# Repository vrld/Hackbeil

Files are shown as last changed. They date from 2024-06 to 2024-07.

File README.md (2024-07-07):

# Hackbeil (/ˈhakˌbaɪ̯l/)

My custom 60 key wireless split keyboard. Inspired by [Lily58](https://github.com/kata0510/Lily58). (Will be) Built with [ergogen](https://ergogen.xyz) and [zmk](https://zmk.dev).

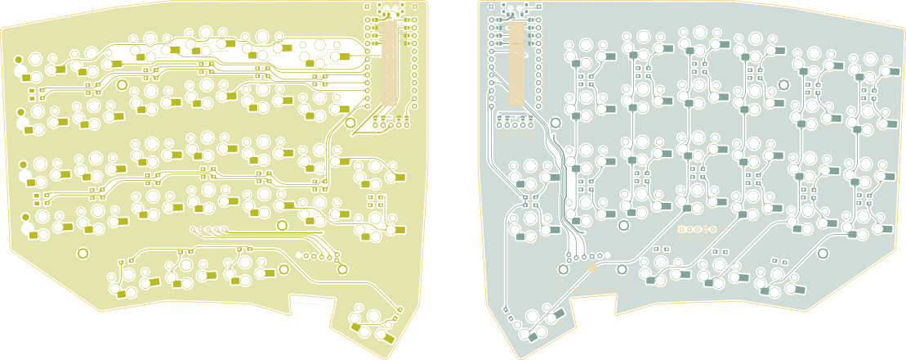
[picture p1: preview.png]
screenshot of the pcb, routed


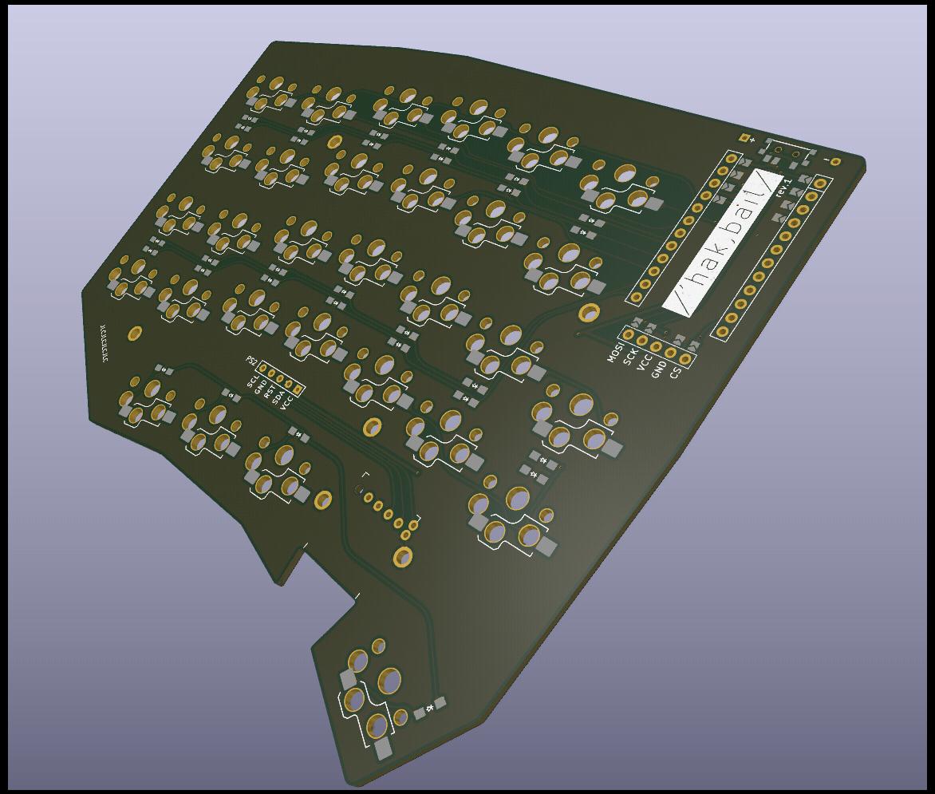
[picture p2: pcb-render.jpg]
rendering of the pcb


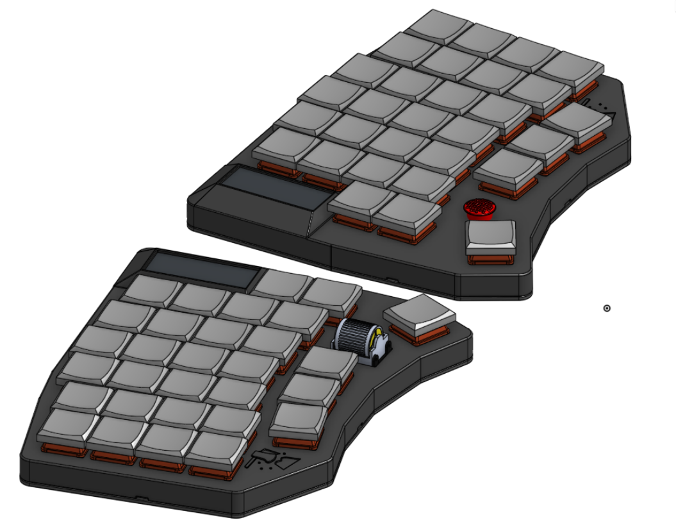
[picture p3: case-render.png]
rendering of the 3d printed case


## Setup

Install ergogen, e.g., with `yarn`:

    yarn global add ergogen

## Building

Using `make`:

    make

The output will be placed in the `build` directory.

Next, use KiCad to add traces or try your luck with freerouting.
That will likely require some modifications to the footprints though.

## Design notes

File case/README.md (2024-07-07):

The case was designed with onshape. Find the document [here](https://cad.onshape.com/documents/a196e7cfe793f017acaf2613/w/5e54595bcd19ec8f7b065f1a/e/1e5f3f1594b05356b8aebbdb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).

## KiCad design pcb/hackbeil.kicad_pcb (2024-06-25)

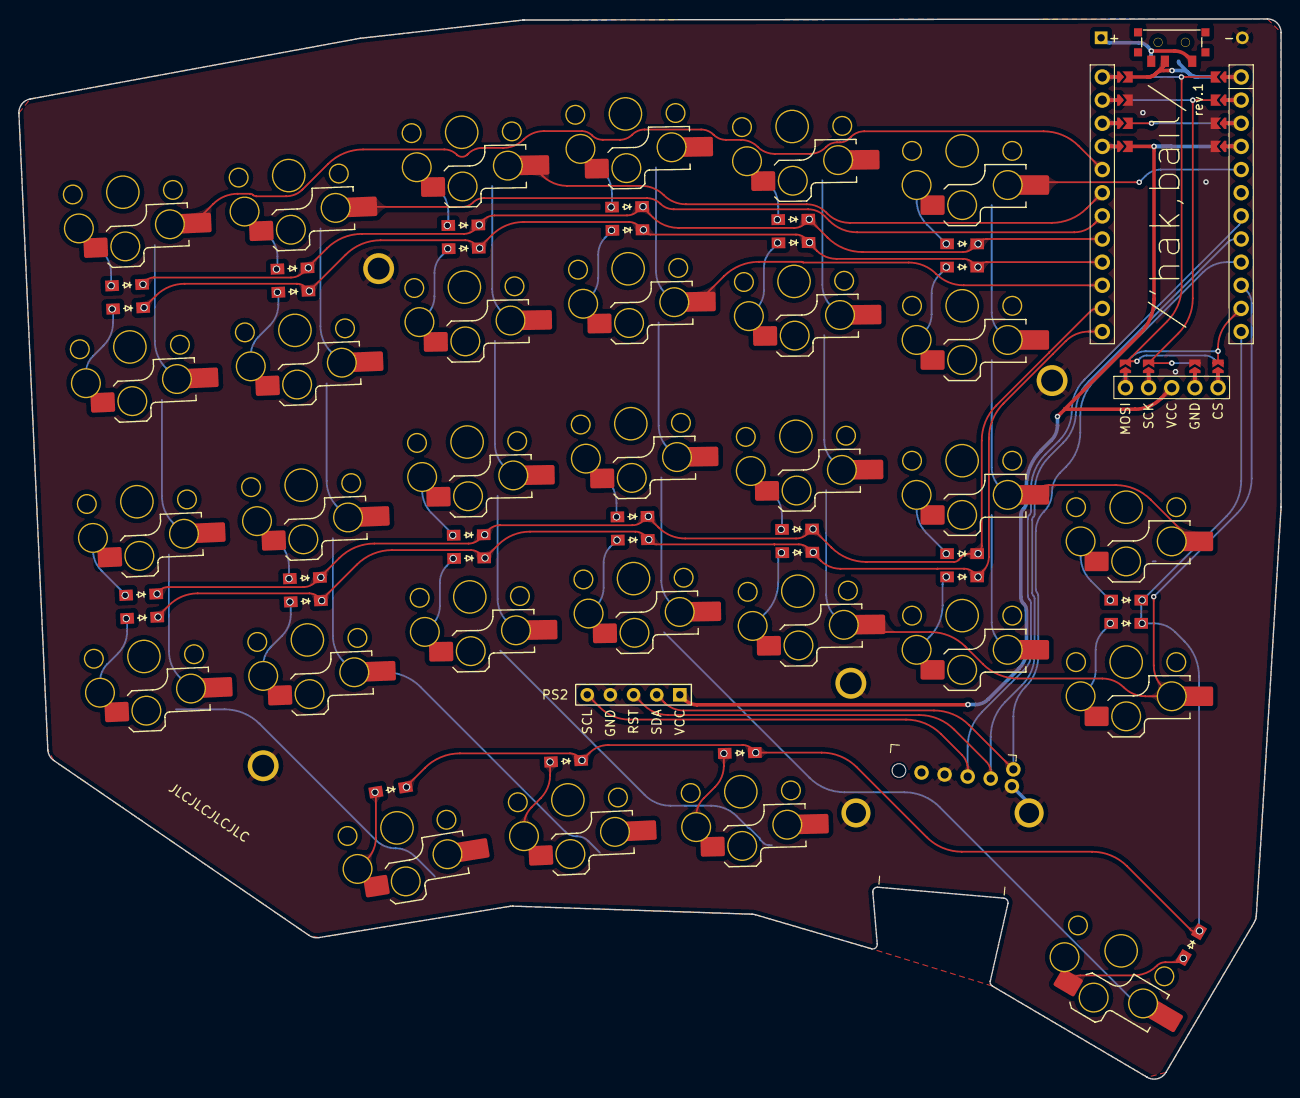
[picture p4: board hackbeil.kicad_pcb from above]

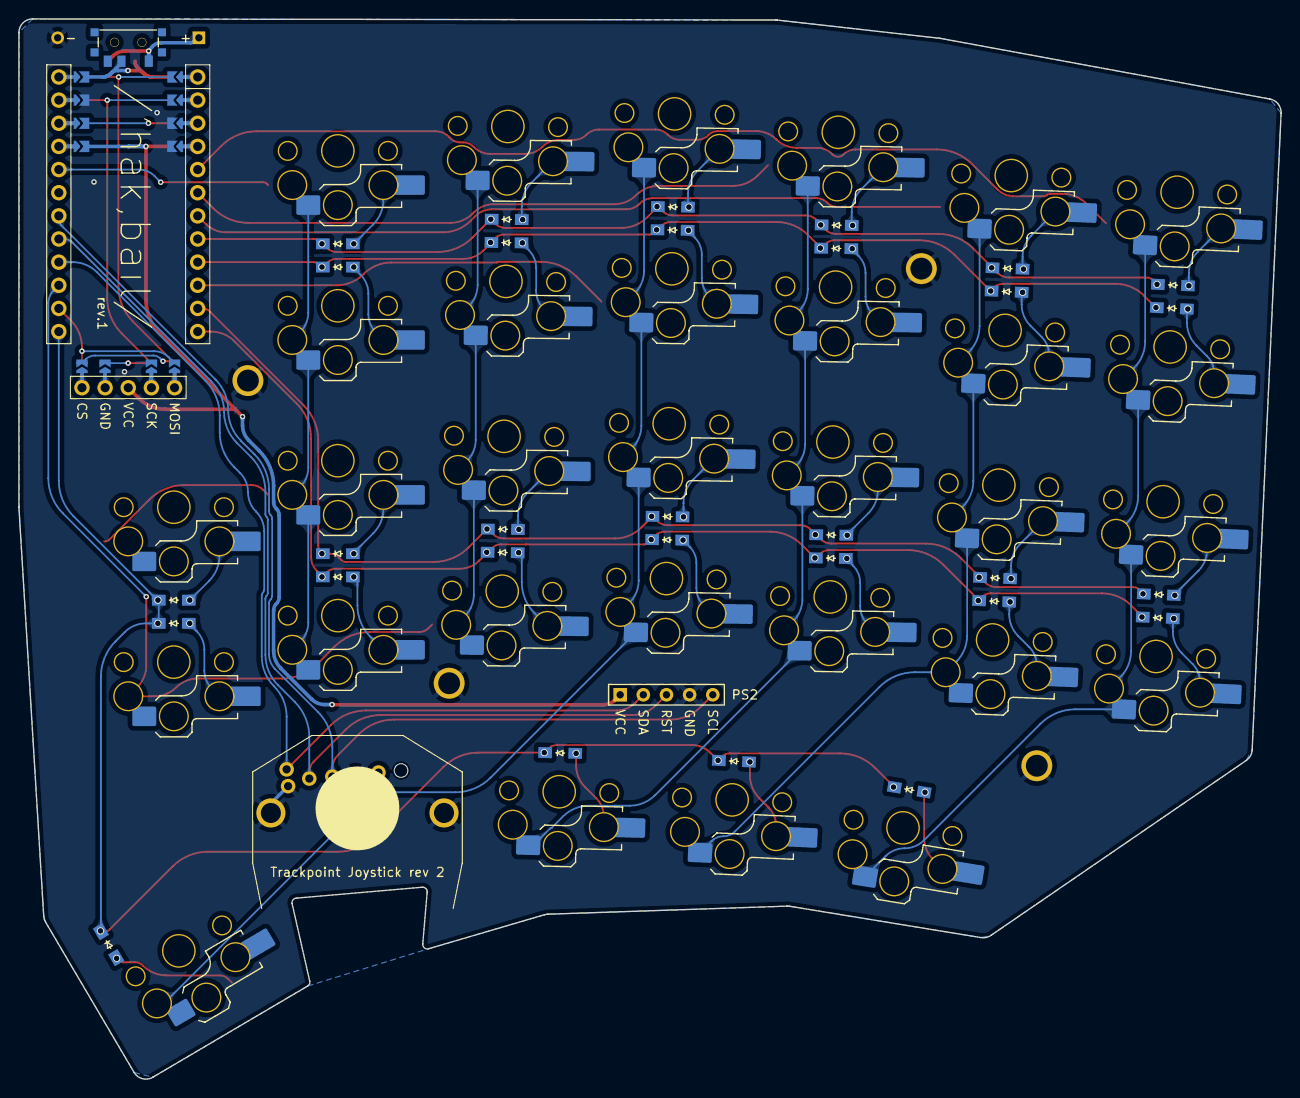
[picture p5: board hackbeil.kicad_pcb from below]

Board: 2 copper layers, 138.5 x 116.3 mm, 71 parts (31 on the bottom side), 55 nets.

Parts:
BAT1: battery
D1, D2, D3, D4, D5, D6, D7, D8, D9, D10, D11, D12, D13, D14, D15, D16, D17, D18, D19, D20, D21, D22, D23, D24, D25, D26, D27, D28, D29, D30: diode
DISP1: nice_view
MCU1: mcu_nice_nano
MH1, MH2, MH3, MH4: mounting_hole
RotaryEncoder_EVQWGD0011: RollerEncoder_EVQWGD001; RotaryEncoder_EVQWGD001
S1, S2, S3, S4, S5, S6, S7, S8, S9, S10, S11, S12, S13, S14, S15, S16, S17, S18, S19, S20, S21, S22, S23, S24, S25, S26, S27, S28, S29, S30: switch_choc_v1_v2
T1: SPDT_C128955
TPH1: trackpoint_header
TPJ1: trackpad_joystick_mounting_holes

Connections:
COL0: MCU1.20, S1.1, S2.1, S3.1, S4.1, S27.1
COL1: MCU1.18, S5.1, S6.1, S7.1, S8.1, S28.1
COL2: MCU1.19, S9.1, S10.1, S11.1, S12.1, S29.1
COL3: MCU1.15, S13.1, S14.1, S15.1, S16.1, S30.1
COL4: MCU1.10, S17.1, S18.1, S19.1, S20.1, S25.1
COL5: MCU1.5, S21.1, S22.1, S23.1, S24.1, S26.1
DISP1_0: DISP1.0, DISP1.5, DISP1.15
DISP1_1: DISP1.1, DISP1.6, DISP1.16
DISP1_3: DISP1.3, DISP1.8, DISP1.18
DISP1_4: DISP1.4, DISP1.9, DISP1.19
GND: BAT1.2, DISP1.13, DISP1.21, MCU1.103, MCU1.104, MCU1.123, RotaryEncoder_EVQWGD0011.C, RotaryEncoder_EVQWGD0011.S2, TPH1.4
NV_CS: DISP1.14, DISP1.20, MCU1.11
NV_MOSI: DISP1.10, DISP1.24, MCU1.101
NV_SCK: DISP1.11, DISP1.23, MCU1.102
RAW: MCU1.124, T1.2
ROW0: D2.1, D2.3, D4.1, D4.3, D6.1, D6.3, D8.1, D8.3, D10.1, D10.3, D12.1, D12.3, MCU1.17
ROW1: D15.1, D15.3, D17.1, D17.3, D19.1, D19.3, D21.1, D21.3, D23.1, D23.3, D25.1, D25.3, MCU1.16
ROW2: D1.1, D1.3, D3.1, D3.3, D5.1, D5.3, D7.1, D7.3, D9.1, D9.3, D11.1, D11.3, MCU1.14
ROW3: D14.1, D14.3, D16.1, D16.3, D18.1, D18.3, D20.1, D20.3, D22.1, D22.3, D24.1, D24.3, MCU1.13
ROW4: D13.1, D13.3, D26.1, D26.3, D27.1, D27.3, D28.1, D28.3, D29.1, D29.3, D30.1, D30.3, MCU1.12
TP_RST: MCU1.8, RotaryEncoder_EVQWGD0011.A, TPH1.3
TP_SCL: MCU1.7, RotaryEncoder_EVQWGD0011.B, TPH1.5
TP_SDA: MCU1.9, RotaryEncoder_EVQWGD0011.S1, TPH1.2
VCC: DISP1.2, MCU1.121, TPH1.1
index_bottom: D22.2, D22.4, S17.2
index_home: D9.2, D9.4, S18.2
index_mod: D29.2, D29.4, S29.2
index_number: D10.2, D10.4, S20.2
index_top: D23.2, D23.4, S19.2
inner_bottom: D24.2, D24.4, S21.2
inner_home: D11.2, D11.4, S22.2
inner_number: D12.2, D12.4, S24.2
inner_top: D25.2, D25.4, S23.2
innest_bottom: D26.2, D26.4, S25.2
innest_home: D13.2, D13.4, S26.2
innest_mod: D30.2, D30.4, S30.2
middle_bottom: D20.2, D20.4, S13.2
middle_home: D7.2, D7.4, S14.2
middle_mod: D28.2, D28.4, S28.2
middle_number: D8.2, D8.4, S16.2
middle_top: D21.2, D21.4, S15.2
outer_bottom: D14.2, D14.4, S1.2
outer_home: D1.2, D1.4, S2.2
outer_number: D2.2, D2.4, S4.2
outer_top: D15.2, D15.4, S3.2
pinky_bottom: D16.2, D16.4, S5.2
pinky_home: D3.2, D3.4, S6.2
pinky_number: D4.2, D4.4, S8.2
pinky_top: D17.2, D17.4, S7.2
ring_bottom: D18.2, D18.4, S9.2
ring_home: D5.2, D5.4, S10.2
ring_mod: D27.2, D27.4, S27.2
ring_number: D6.2, D6.4, S12.2
ring_top: D19.2, D19.4, S11.2
switch_from: BAT1.1, T1.1

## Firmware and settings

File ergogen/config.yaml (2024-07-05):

# ref: https://docs.ergogen.xyz/
# tut: https://flatfootfox.com/ergogen-introduction/
meta:
  engine: "4.1.0"

units:
  # choc spacing
  kx: cx
  ky: cy

  # size of the switch hole in the top plate
  hx: 13.8 + .3
  hy: 13.8 + .3

  # 4 mm padding between keys and board edge
  px: kx + 4
  py: ky + 4

  # wall padding
  wx: kx + 7
  wy: ky + 7

  # lip padding
  wpx: wx + (wx - px) / 2
  wpy: wy + (wy - py) / 2

  # controller size and distance to the keys
  mcu_height: 34
  mcu_padding: 5
  mcu_thickness: 3

  # trackpoint -- just the joystick part; the controller board will be glued to the backside of the shield
  trackpoint_width: 23
  trackpoint_height: 19
  trackpoint_stagger: 7
  trackpoint_offset: -.5
  trackpoint_bottom_to_stick: 11
  trackpoint_joystick_radius: 3.5

  # case parameters
  bottom_height: 2
  bottom_to_pcb: 2
  pcb_height: 1.6

  lip_height: 2

  # ref: https://keycapsss.com/media/image/12/7a/49/kailh-choc-switch-low-profile-dimensions.png
  choc_top_side_length: 15
  choc_nose_to_rim: 1.3
  choc_pcb_to_rim: 2.2
  choc_pcb_to_nose: choc_pcb_to_rim - choc_nose_to_rim
  choc_rim_height: 0.8

  case_height: bottom_height + bottom_to_pcb + pcb_height + choc_pcb_to_rim
  mounting_hole_radius: 1
  standoff_radius: 2

  usb_cutout_height: bottom_to_pcb
  usb_cutout_shift: bottom_height
  on_off_switch_height: 1.5

  battery_width: 12
  battery_height: 30
  battery_thickness: 3

  nice_view_width: 14
  nice_view_height: 36
  nice_view_thickness: 2.9

  # encoder cutout size
  ex: 16.8 + .3
  ey: 14 + .3

points:
  zones:

    # 6x4 matrix, plus 2 function keys
    matrix:
      anchor.shift: [130, -130]

      key:
        padding: ky
        spread: kx
        tags: [switch]

      columns:
        outer.key:
          splay: 2.6
          column_net: COL0
        pinky.key:
          stagger: 1
          splay: -.3
          column_net: COL1
        ring.key:
          stagger: 4
          splay: -1.3
          column_net: COL2
        middle.key:
          stagger: 1.7
          column_net: COL3
        index.key:
          stagger: -1.7
          splay: -.3
          column_net: COL4
        inner.key:
          stagger: -2.9
          splay: -.7
          column_net: COL5
        # only two function keys in the innest column
        innest:
          rows:
            number: $unset
            top: $unset
            home:
              row_net: ROW4
              column_net: COL5
            bottom:
              row_net: ROW4
              column_net: COL4
          key:
            stagger: -ky * .3

      rows:
        bottom.row_net: ROW3
        home:
          tags: [switch, diode-below]
          row_net: ROW2
        top.row_net: ROW1
        number:
          row_net: ROW0
          tags: [switch, diode-below]

    # thumb cluster with four modifier keys
    thumb:
      anchor:
        ref: matrix_pinky_bottom
        shift: [.5 kx, -py]
      key.tags: [switch]
      rows.mod.row_net: ROW4
      columns:
        ring.key:
          splay: 7
          column_net: COL0
        middle.key:
          splay: -6.6
          column_net: COL1
        index.key:
          splay: -1.2
          column_net: COL2
        # space for a trackpoint
        inner.rows.mod.skip: true
        # the innest one is offset and rotated
        innest.key:
          splay: -32
          shift: [.7 kx, -14]
          column_net: COL3
          tags: [switch, extrawurst]

    # board components
    mcu:
      anchor:
        - ref: matrix_innest_bottom
          affect: xr
          shift: mcu_padding
        - ref: matrix_middle_number
          affect: y
          shift: (ky-mcu_height)/2
      rows.mcu:
      columns.mcu.key:
        tags: [mcu]

    trackpoint:
      anchor:
        aggregate.parts: [thumb_innest_mod, thumb_index_mod]
        affect: xy
        shift: [trackpoint_offset, trackpoint_stagger]
      rows.tp:
      columns.tp.key:
        tags: [trackpoint]

    # mounting holes
    mounting:
      key:
        padding: 3ky
        spread: 4kx
        tags: [mounting hole]

      anchor.ref: matrix_pinky_bottom

      columns:
        outer:
          key.adjust.shift: [-.3kx, -.8ky]
          rows.top.shift: [.825kx, 3]
        middle:
          key.adjust.shift: [-.7kx, -.42ky]
          rows.top.shift: [1.3kx, -1.1ky]

      rows:
        bottom:
        top:
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

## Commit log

2024-06-14 Add PCB, tweak layout
2024-06-16 SMD diode only
2024-06-16 remove unused features from footprint
2024-06-16 Add trackpoint header footprint
2024-06-16 Move diodes to more convenient positions
2024-06-16 Flip pin order for rows and columns
    This makes routing easier
    [config.yaml]
2024-06-16 PCB pre-routing
    [hackbeil.kicad_pcb]
2024-06-17 Fix wiring
2024-06-17 Refactor OLED header footprint
2024-06-20 Tweak footprints
2024-06-20 Tweak board layout
2024-06-20 Prepare for wiring
2024-06-20 Hand routed PCB
    [hackbeil.kicad_pcb]
2024-06-20 Add teardrops and smooth traces
    [hackbeil.kicad_pcb]
2024-06-22 Add EVQWGD001 encoder, try freerouting
2024-06-22 Traced by combination of freerouting and manual routing
    [hackbeil.kicad_pcb]
2024-06-22 Add teardrops
    [hackbeil.kicad_pcb]
2024-06-22 Fancy rounded tracks (thanks, Mitxela!)
    [hackbeil.kicad_pcb]
2024-06-23 Add keyplate, prepare 3d printed case
    [keyplate_left.kicad_pcb, keyplate_right.kicad_pcb]
2024-06-25 Final routing and top plates
    [hackbeil.kicad_pcb, keyplate_left.kicad_pcb, keyplate_right.kicad_pcb]
2024-07-07 Add case
